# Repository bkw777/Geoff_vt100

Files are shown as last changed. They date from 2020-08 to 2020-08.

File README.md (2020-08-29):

# Geoff's VT100 Terminal  
BKW respin, NOT WORKING, needs Firmware.  
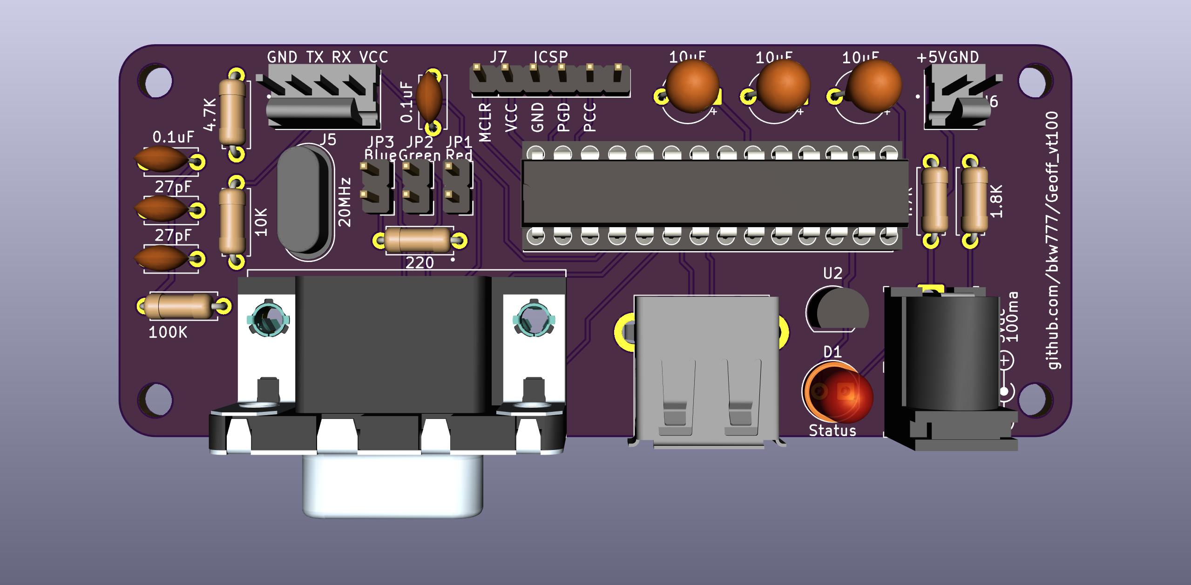
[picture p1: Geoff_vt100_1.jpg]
  
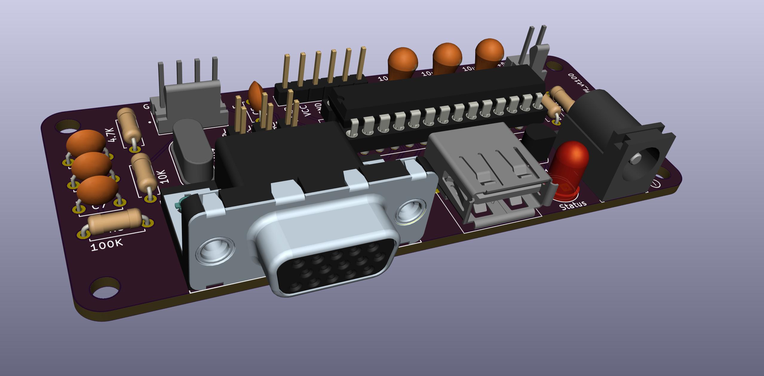
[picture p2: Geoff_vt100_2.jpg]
  
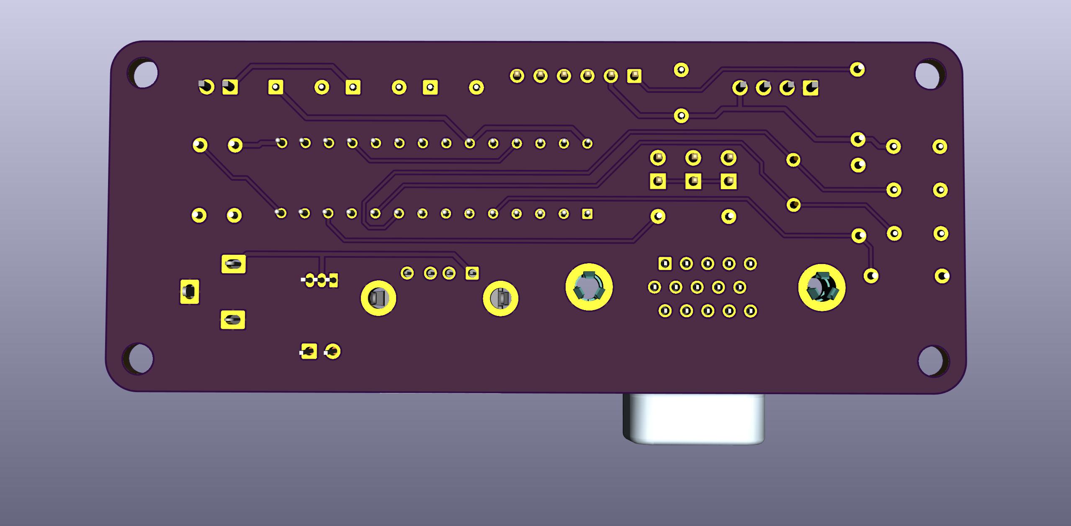
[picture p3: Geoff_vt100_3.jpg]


PCB from OSHPark: <https://oshpark.com/shared_projects/MvDzzk9e>  
Parts from Digi-Key: <https://www.digikey.com/short/zrdw9v>

## Credits  
This version aims to combine elements from the following other versions:  

* [Geoff Graham](https://geoffg.net/terminal.html)  
 The original version  
* [Peter Hizalev](https://github.com/petrohi/terminal)  
 "v2.0" with rearranged PCB and modified firmware  
* [David Hansel](https://github.com/dhansel/TerminalUSB)   
 USB keyboard instead of PS/2  

## Goal  
Changes in this version:
 - remove ps/2 port
 - change usb port to type-a female
 - barrel power jack
 - remove all GND traces
 - add copper pours for GND on both sides
 - optimize routes, increase clearances, and tweak footprints to get full copper pour coverage  
 - DigiKey BOM  
 - Fully self-contained KiCAD files  

## Status  
 PCB: done but not tested  
  need to clean out un-used components and models  
  need to include a few more symbols & footprints  

 Firmware: has not been touched at all yet. Firmware probably does not work currently, as it is just a copy of Peter Hizalev's firmware, but the PCB no longer matches that PCB.  
  Peter Hizalev PCB uses a 20mhz crystal, which this PCB has  
  This PCB started from Peter's, so if the firmware requires any other hardware differences, like different pinout to the mcu, this board should match  
  Peter Hizalev firmware expects keyboard on PS/2, which this PCB does not have  

 TODO:  
  Generate diffs between the 3 source versions above to understand the changes each made vs the original  
  Combine Peter Hizalev and David Hansel changes

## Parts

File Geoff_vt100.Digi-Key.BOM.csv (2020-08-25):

Index | Quantity | Part Number | Manufacturer Part Number | Description | Customer Reference | Available | Backorder | Unit Price | Extended Price USD
1 | 1 | 609-5181-ND | ICD15S13E4GX00LF | CONN DSUB HD RCPT 15POS R/A SLDR |  | 1 | 0 | 1.29000 | 1.29
2 | 1 | PIC32MX270F256B-I/SP-ND | PIC32MX270F256B-I/SP | IC MCU 32BIT 256KB FLASH 28SDIP |  | 1 | 0 | 4.03000 | 4.03
3 | 1 | MCP1700-3302E/TO-ND | MCP1700-3302E/TO | IC REG LINEAR 3.3V 250MA TO92-3 |  | 1 | 0 | 0.37000 | 0.37
4 | 1 | 887-1248-ND | 9B-20.000MEEJ-B | CRYSTAL 20.0000MHZ 18PF T/H |  | 1 | 0 | 0.48000 | 0.48
5 | 1 | 1080-1064-ND | HLMPD150A | LED RED DIFFUSED T-1 3/4 T/H |  | 1 | 0 | 0.46000 | 0.46
6 | 2 | 490-8671-ND | RDE5C1H270J0P1H03B | CAP CER 27PF 50V NP0 RADIAL |  | 2 | 0 | 0.49000 | 0.98
7 | 2 | 478-7334-1-ND | SR215C104KAATR1 | CAP CER 0.1UF 50V X7R RADIAL |  | 2 | 0 | 0.22000 | 0.44
8 | 3 | 445-173437-1-ND | FG26X7R1E106KRT06 | CAP CER 10UF 25V X7R RADIAL |  | 3 | 0 | 0.73000 | 2.19
9 | 1 | CF14JT220RCT-ND | CF14JT220R | RES 220 OHM 1/4W 5% AXIAL |  | 1 | 0 | 0.10000 | 0.10
10 | 1 | CF14JT10K0CT-ND | CF14JT10K0 | RES 10K OHM 1/4W 5% AXIAL |  | 1 | 0 | 0.10000 | 0.10
11 | 1 | CF14JT100KCT-ND | CF14JT100K | RES 100K OHM 1/4W 5% AXIAL |  | 1 | 0 | 0.10000 | 0.10
12 | 1 | A1922-ND | 640456-4 | CONN HEADER VERT 4POS 2.54MM |  | 1 | 0 | 0.23000 | 0.23
13 | 1 | A1921-ND | 640456-2 | CONN HEADER VERT 2POS 2.54MM |  | 1 | 0 | 0.11000 | 0.11
14 | 1 | ED11091-ND | 110-47-328-41-001000 | CONN IC DIP SOCKET 28POS GOLD |  | 1 | 0 | 1.38000 | 1.38
15 | 1 | 2057-PH1-14-UA-ND | PH1-14-UA | CONN HEADER VERT 14POS 2.54MM |  | 1 | 0 | 0.21000 | 0.21
16 | 4 | CF14JT4K70CT-ND | CF14JT4K70 | RES 4.7K OHM 1/4W 5% AXIAL |  | 4 | 0 | 0.10000 | 0.40
17 | 1 | CP-102A-ND | PJ-102A | CONN PWR JACK 2X5.5MM SOLDER |  | 1 | 0 | 0.64000 | 0.64
18 | 1 | 380-1412-ND | SS-52100-001 | CONN RCPT USB2.0 TYPEA 4POS R/A |  | 1 | 0 | 0.46000 | 0.46
19 | 1 | CF14JT1K80CT-ND | CF14JT1K80 | RES 1.8K OHM 1/4W 5% AXIAL |  | 1 | 0 | 0.10000 | 0.10

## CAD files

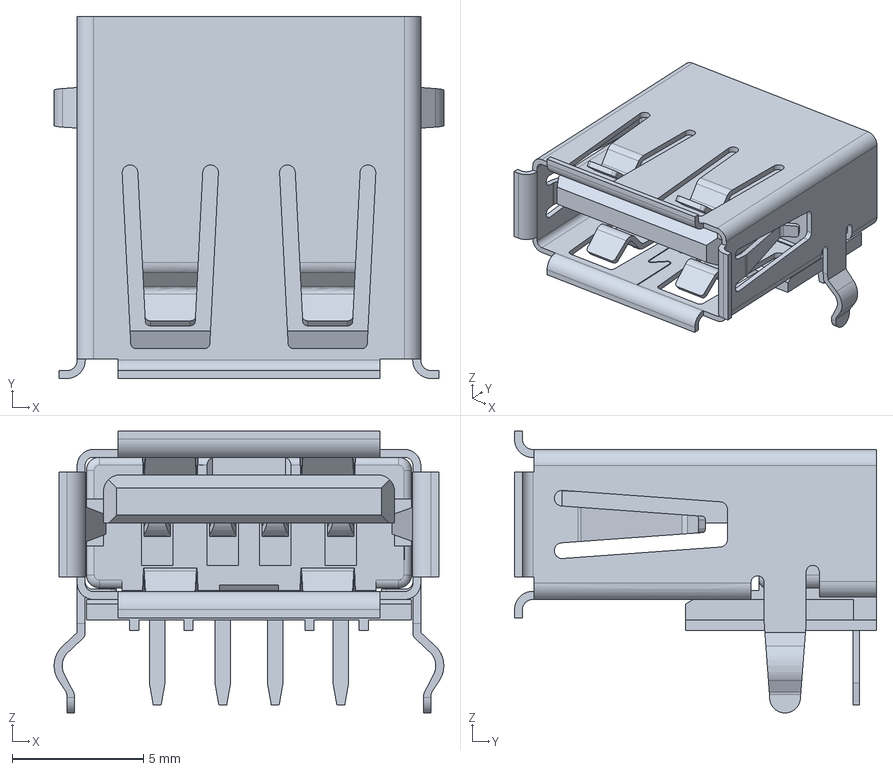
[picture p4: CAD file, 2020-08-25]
pcb/3d/USB-A_female_horiz_thru.step
14.9 x 13.8 x 10.7 mm

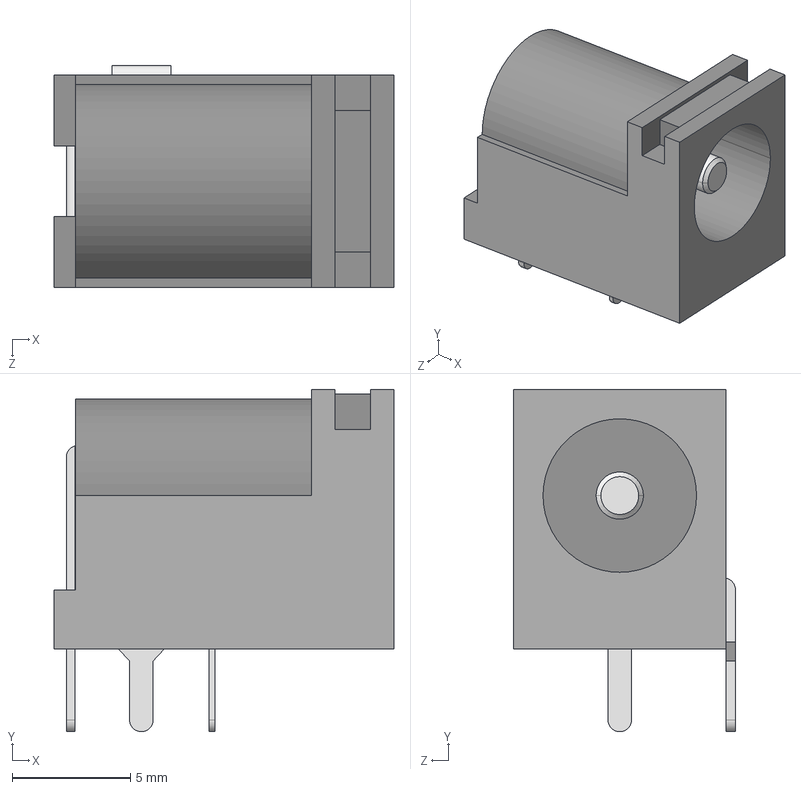
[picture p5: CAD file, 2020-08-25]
pcb/3d/CUI_DEVICES_PJ-102A.step
14.4 x 14.5 x 9.40 mm

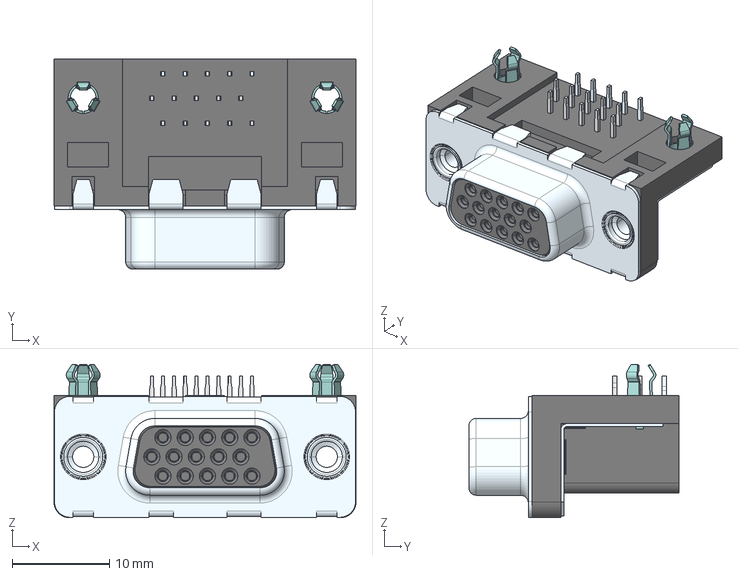
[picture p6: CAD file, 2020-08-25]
pcb/3d/ICD15S13E4GX00LF.step
31.0 x 21.6 x 15.8 mm

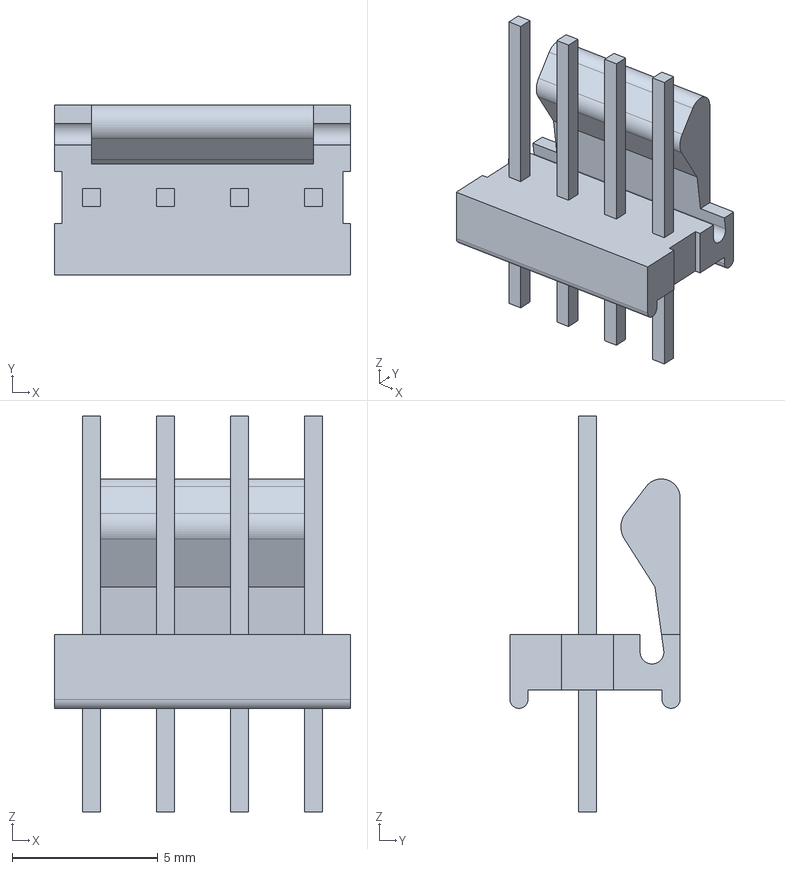
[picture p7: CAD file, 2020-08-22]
pcb/3d/c-3-641215-4-z-3d.stp
10.2 x 5.84 x 13.6 mm

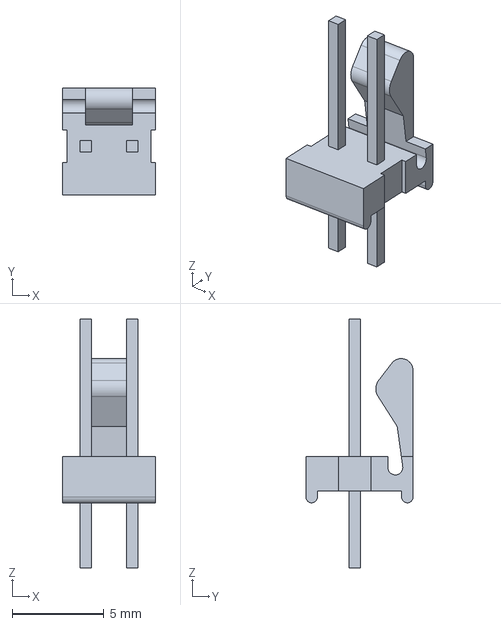
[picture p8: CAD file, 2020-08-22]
pcb/3d/c-3-641215-2-z-3d.stp
5.08 x 5.84 x 13.6 mm

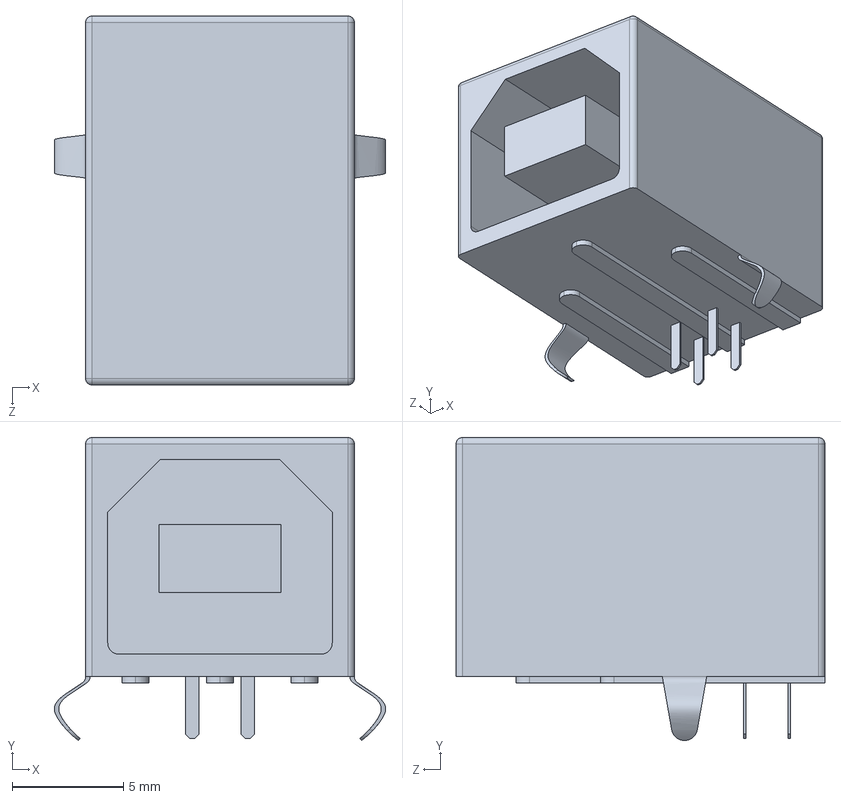
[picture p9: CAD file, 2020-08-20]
pcb/3d/USB type-B female PCB.STEP
14.9 x 13.6 x 16.6 mm

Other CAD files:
pcb/3d/USB-A_female_horiz_thru_c.step

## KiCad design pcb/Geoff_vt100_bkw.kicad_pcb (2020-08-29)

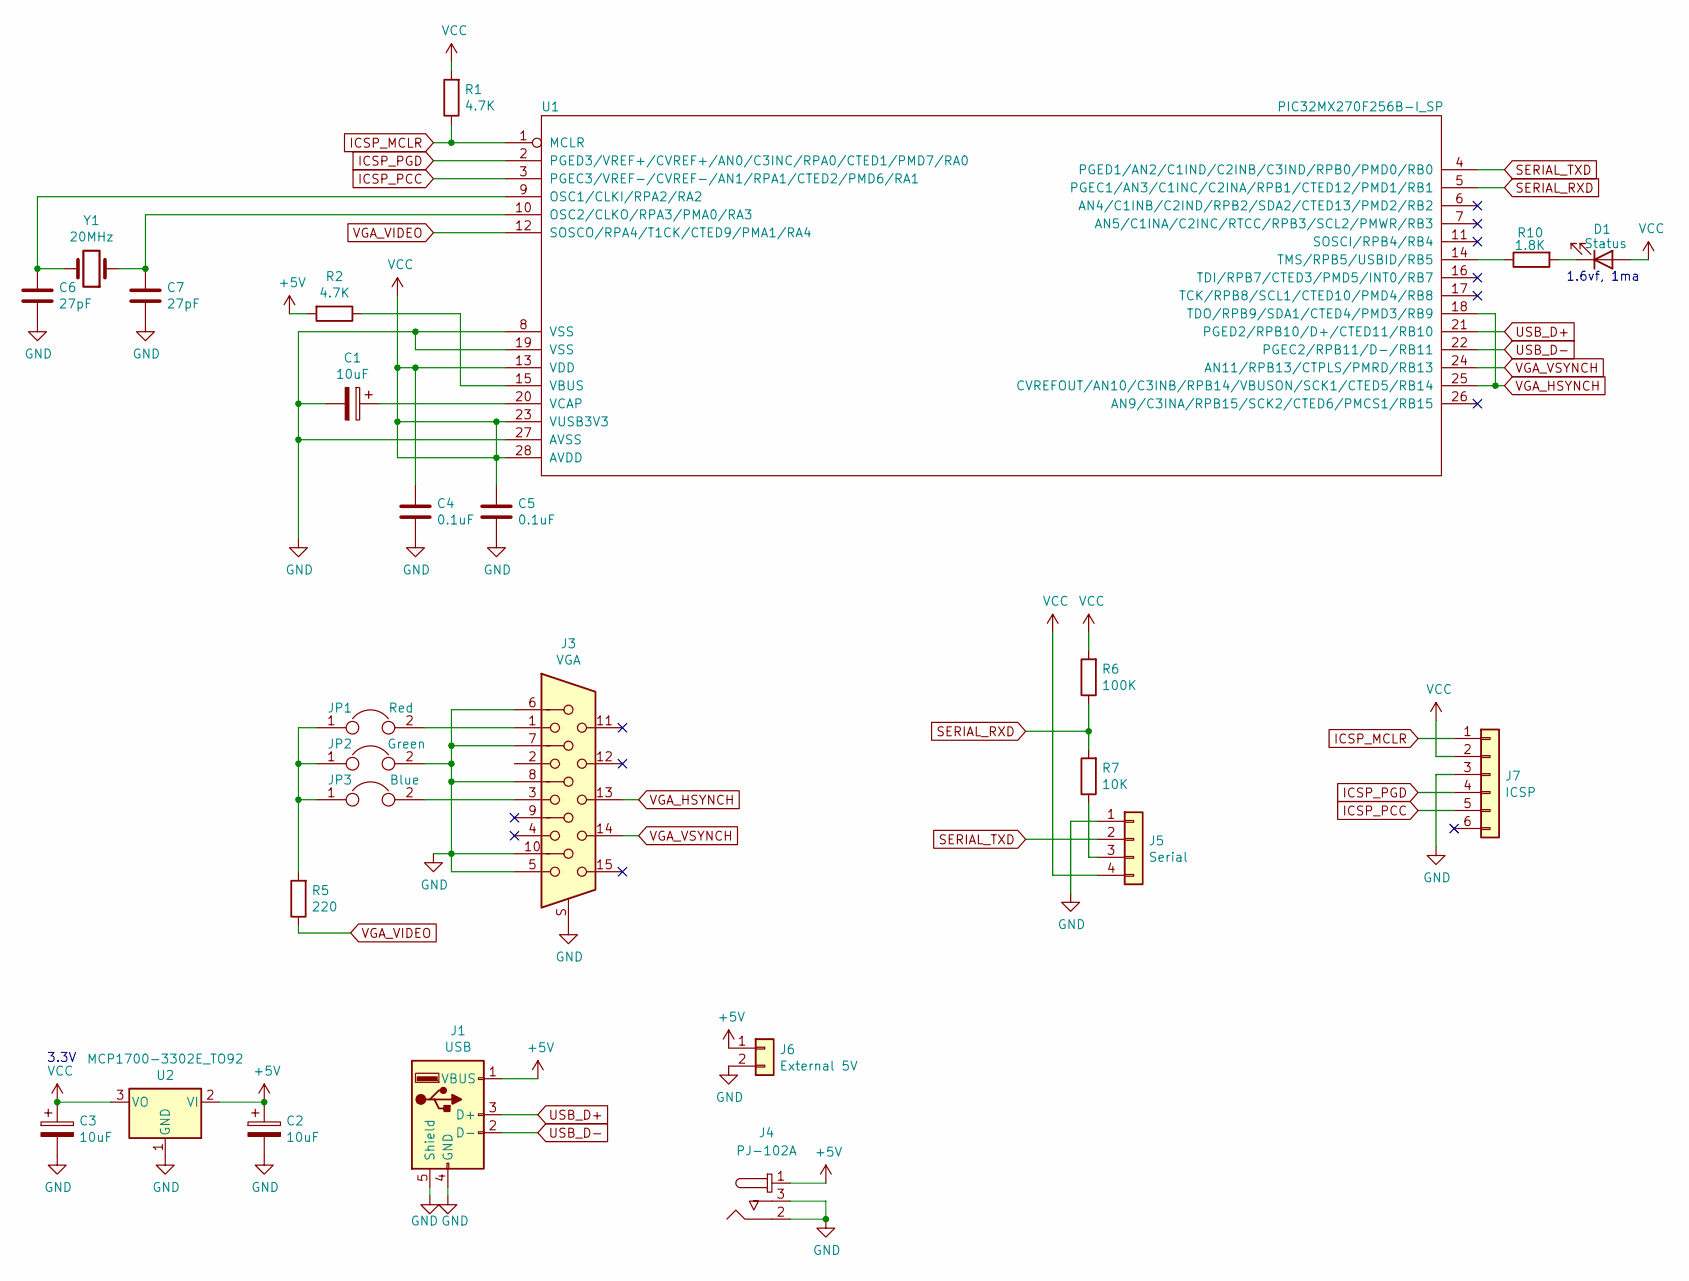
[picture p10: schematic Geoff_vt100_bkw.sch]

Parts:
C1, C2, C3: 10uF; CP_Radial_Tantal_D5.0mm_P5.00mm
C4, C5: 0.1uF; C_Disc_D5.0mm_W2.5mm_P5.00mm
C6, C7: 27pF; C_Disc_D5.0mm_W2.5mm_P5.00mm
D1: Status; LED_D5.0mm
J1: USB; USB_A_Female_UE27AC54100
J3: VGA; ICD15S13E4GX00LF
J4: PJ-102A; Barrel_Jack_5.5mmODx2.1mmID_PJ-102A; MPN PJ-102A; Digi-Key_PN CP-102A-ND
J5: Serial; TE_3-641215-4
J6: External 5V; TE_3-641215-2
J7: ICSP; Pin_Header_Straight_1x06_Pitch2.54mm
JP1: Red; Pin_Header_Straight_1x02_Pitch2.54mm
JP2: Green; Pin_Header_Straight_1x02_Pitch2.54mm
JP3: Blue; Pin_Header_Straight_1x02_Pitch2.54mm
R1, R2: 4.7K; R_Axial_DIN0207_L6.3mm_D2.5mm_P7.62mm_Horizontal
R5: 220; R_Axial_DIN0207_L6.3mm_D2.5mm_P7.62mm_Horizontal
R6: 100K; R_Axial_DIN0207_L6.3mm_D2.5mm_P7.62mm_Horizontal
R7: 10K; R_Axial_DIN0207_L6.3mm_D2.5mm_P7.62mm_Horizontal
R10: 1.8K; R_Axial_DIN0207_L6.3mm_D2.5mm_P7.62mm_Horizontal
U1: PIC32MX270F256B-I_SP; DIP-28_W7.62mm_Socket
U2: MCP1700-3302E_TO92; TO-92_HandSolder
Y1: 20MHz; Crystal_HC49-4H_Vertical

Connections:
+5V: C2.1, J1.1 (VBUS), J4.1, J6.1, R2.2, U2.2 (VI)
ICSP_MCLR: J7.1, R1.1, U1.1 (MCLR)
ICSP_PCC: J7.5, U1.3 (PGEC3/VREF-/CVREF-/AN1/RPA1/CTED2/PMD6/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)
ICSP_PGD: J7.4, U1.2 (PGED3/VREF+/CVREF+/AN0/C3INC/RPA0/CTED1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)
unnamed: C1.1, U1.20 (VCAP)
unnamed: C6.1, U1.9 (OSC1/CLKI/RPA2/RA2), Y1.2
unnamed: C7.1, U1.10 (OSC2/CLKO/RPA3/PMA0/RA3), Y1.1
unnamed: D1.1 (K), R10.2
unnamed: J3.1, JP1.2
unnamed: J3.3, JP3.2
unnamed: J5.3, R7.1
unnamed: JP1.1, JP2.1, JP3.1, R5.2
unnamed: R2.1, U1.15 (VBUS)
unnamed: R10.1, U1.14 (TMS/RPB5/USBID/RB5)
SERIAL_RXD: R6.1, R7.2, U1.5 (PGEC1/AN3/C1INC/C2INA/RPB1/CTED12/PMD1/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)
SERIAL_TXD: J5.2, U1.4 (PGED1/AN2/C1IND/C2INB/C3IND/RPB0/PMD0/R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)
USB_D+: J1.3 (D+), U1.21 (PGED2/RPB10/D+/CTED11/RB10)
USB_D-: J1.2 (D-), U1.22 (PGEC2/RPB11/D-/RB11)
VCC: C3.1, C4.1, C5.1, D1.2 (A), J5.4, J7.2, R1.2, R6.2, U1.13 (VDD), U1.23 (VUSB3V3), U1.28 (AVDD), U2.3 (VO)
VGA_HSYNCH: J3.13, U1.18 (TDO/RPB9/SDA1/CTED4/PMD3/RB9), U1.25 (CVREFOUT/AN10/C3INB/RPB14/VBUSON/SCK1/C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)
VGA_VIDEO: R5.1, U1.12 (SOSCO/RPA4/T1CK/CTED9/PMA1/RA4)
VGA_VSYNCH: J3.14, U1.24 (AN11/RPB13/CTPLS/PMRD/RB13)

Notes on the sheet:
3.3V
1.6vf, 1ma

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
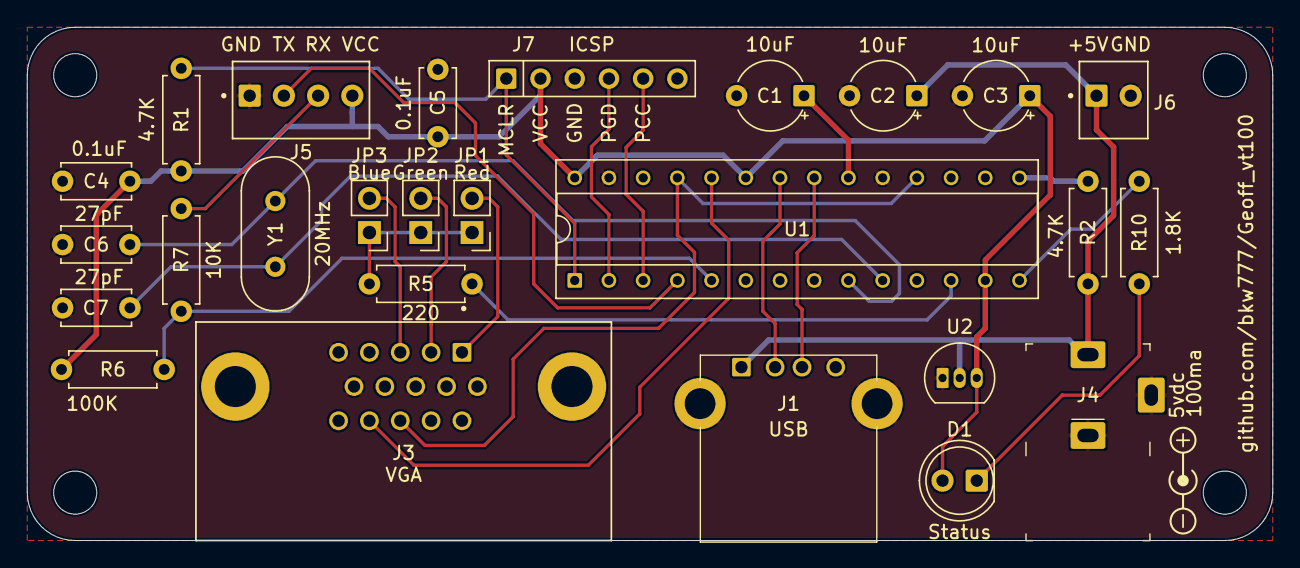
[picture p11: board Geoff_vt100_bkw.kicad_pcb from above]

Board: 2 copper layers, 92.5 x 38.1 mm, 26 parts (0 on the bottom side), 24 nets.

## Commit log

2020-08-20 ground planes instead of traces, fatter traces for power
    [USB type-B female PCB.STEP, terminal.kicad_pcb, terminal.sch]
2020-08-22 footprint tweaks
    [terminal.kicad_pcb]
2020-08-22 rename, add oshpark and digikey links
    [CUI_MD-60SM.step, USB type-B female PCB.STEP, c-3-641215-2-z-3d.stp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]
2020-08-25 usb keyboard, barrel power
    [CUI_DEVICES_PJ-102A.step, CUI_MD-60SM.step, Geoff_vt100.Digi-Key.BOM.csv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]
2020-08-29 usb keyboard
    [Geoff_vt100_bkw.kicad_pcb]
